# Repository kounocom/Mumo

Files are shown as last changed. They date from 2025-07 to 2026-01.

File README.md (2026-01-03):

# Mumo - Compact ICM-45686+QMC6309 Module

A compact 13×18mm IMU module featuring the TDK InvenSense ICM-45686 6-axis IMU with integrated 32.768kHz clock and QST QMC6309 3-axis magnetometer.

PCB Image

## Features

- **Compact Design**: 13×18mm form factor
- **High-Performance IMU**: TDK InvenSense ICM-45686 6-axis IMU with integrated 32.768kHz clock for precise output timesteps
- **3-Axis Magnetometer**: QST QMC6309 for 9-DOF sensing
- **Connectivity**: Castellated holes for flat mounting on compatible carrier PCBs
- **Power Optimization**: Solder bridges to disconnect I2C pull-ups for improved power efficiency when using SPI
- **Easily Configurable I2C Address**: Solder bridge for SD0 pin to change I2C address from `0x69` to `0x68`

## Compatibility

The pinout is **mostly compatible** with popular BMI160 and LSM6DS3 modules found on Amazon and AliExpress, with these differences:

- **OSDO**: Functions as VIN on AliExpress modules
- **CLK_CTL**: Not present on AliExpress modules

## Schematic

Schematic

## Ordering Information

### Important Notes

⚠️ **IMU Pin 7**: Pin 7 of the IMU is intentionally disconnected as recommended for the ICM-45686. If substituting with another IMU that requires pin 7 as GND, modify the PCB to connect IMU pin 7 to ground.

⚠️ **Surface Finish**: ENIG surface finish is recommended for easier soldering and better reliability with the BGA magnetometer.

⚠️ **Castellated Holes**: While castellated holes significantly increase manufacturing cost, they enable flat soldering onto carrier boards. Consider your application requirements before deciding to omit them.

## License

See [LICENSE.md](LICENSE.md) for license information.

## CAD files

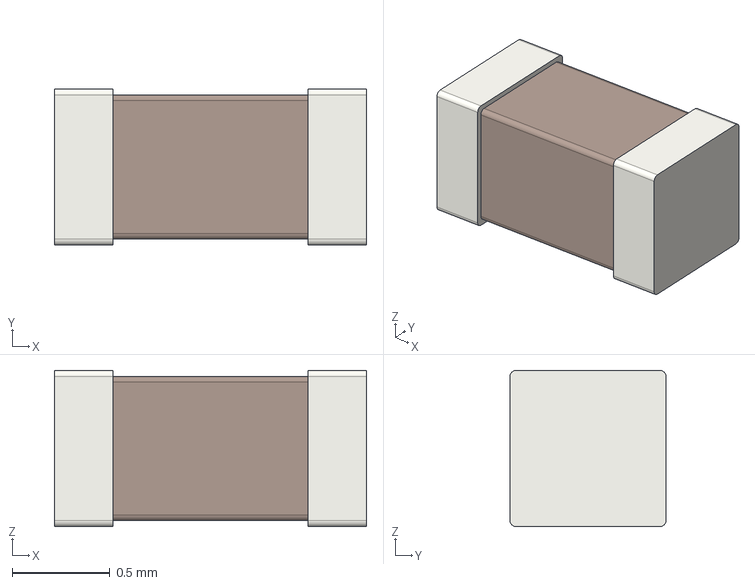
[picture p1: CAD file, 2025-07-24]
Mumo Data/Mumo Models/C_0603_1608Metric.step
1.60 x 0.8 x 0.8 mm

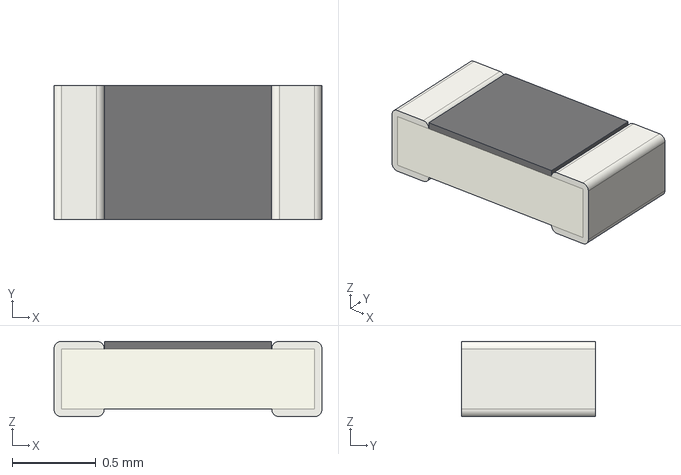
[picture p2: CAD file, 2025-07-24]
Mumo Data/Mumo Models/R_0603_1608Metric.step
1.60 x 0.8 x 0.45 mm

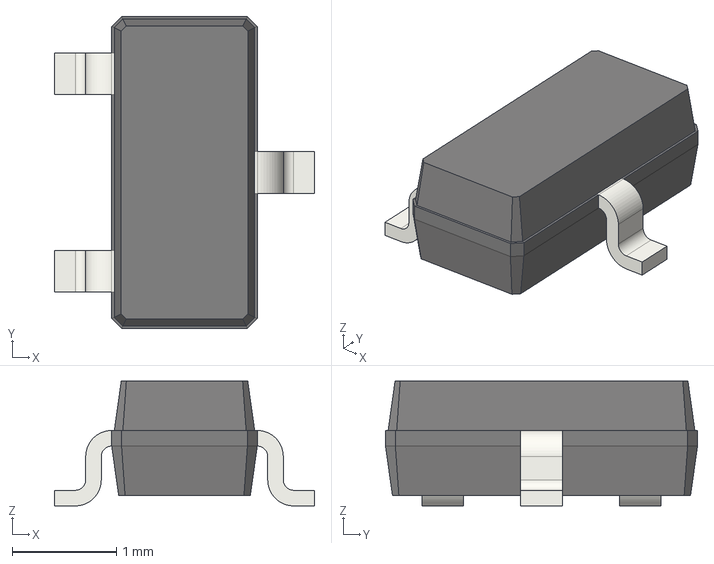
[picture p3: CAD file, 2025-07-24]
Mumo Data/Mumo Models/SOT-23.step
2.50 x 3.00 x 1.20 mm

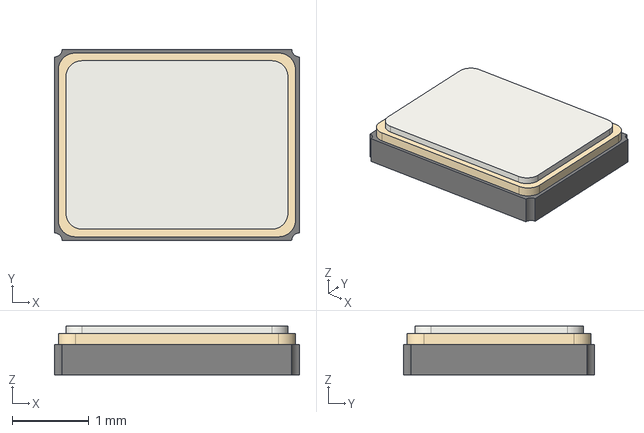
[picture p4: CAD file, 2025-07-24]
Mumo Data/Mumo Models/Crystal_SMD_3225-4Pin_3.2x2.5mm.step
3.20 x 2.50 x 0.64 mm

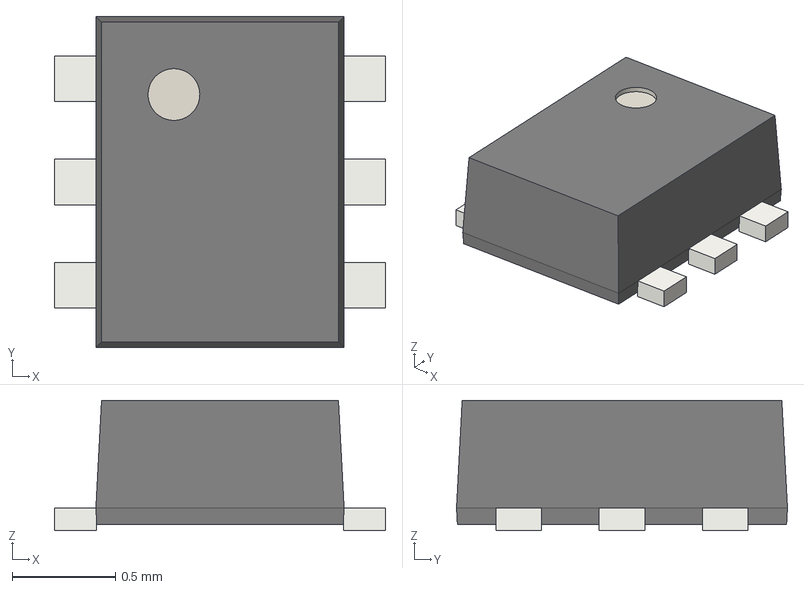
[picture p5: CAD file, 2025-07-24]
Mumo Data/Mumo Models/SOT-563.step
1.60 x 1.60 x 0.63 mm

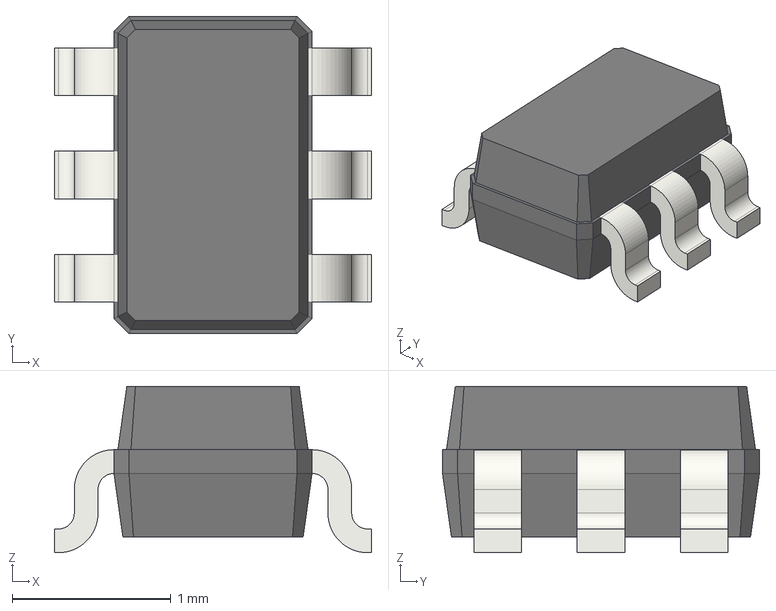
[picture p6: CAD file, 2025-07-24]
Mumo Data/Mumo Models/SOT-363_SC-70-6.step
2.00 x 2.00 x 1.05 mm

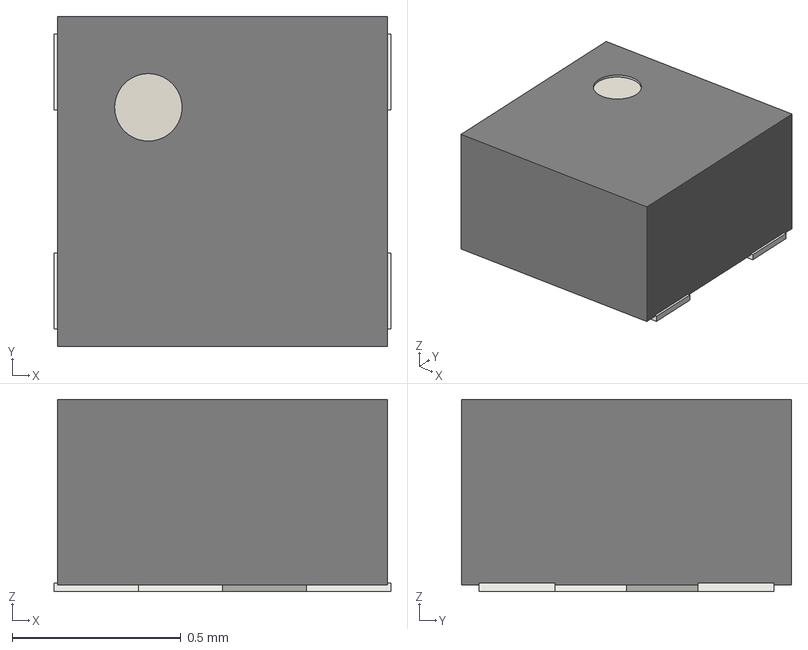
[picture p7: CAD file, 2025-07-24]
Mumo Data/Mumo Models/UDFN-4-1EP_1x1mm_P0.65mm_EP0.48x0.48mm.step
1.00 x 0.98 x 0.57 mm

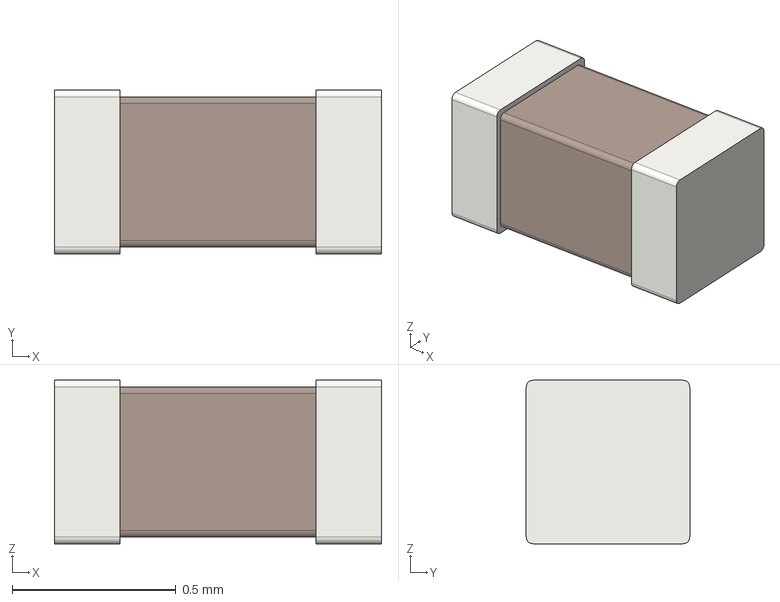
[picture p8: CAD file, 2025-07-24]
Mumo Data/Mumo Models/C_0402_1005Metric.step
1.00 x 0.5 x 0.5 mm

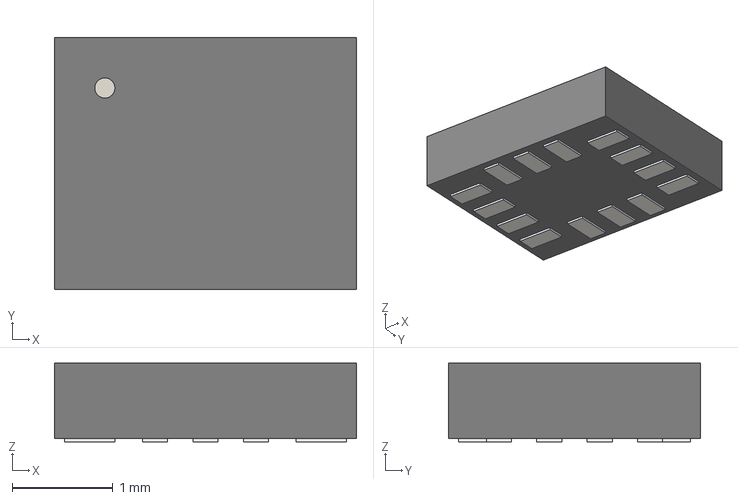
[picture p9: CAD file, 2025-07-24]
Mumo Data/Mumo Models/Bosch_LGA-14_3x2.5mm_P0.5mm.step
3.00 x 2.50 x 0.78 mm

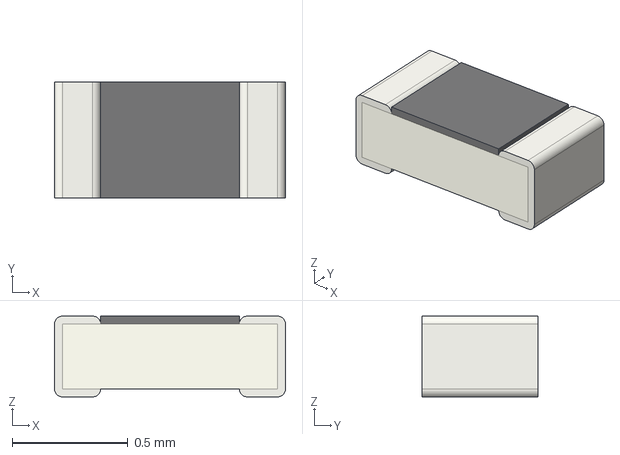
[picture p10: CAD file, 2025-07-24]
Mumo Data/Mumo Models/R_0402_1005Metric.step
1.00 x 0.5 x 0.35 mm

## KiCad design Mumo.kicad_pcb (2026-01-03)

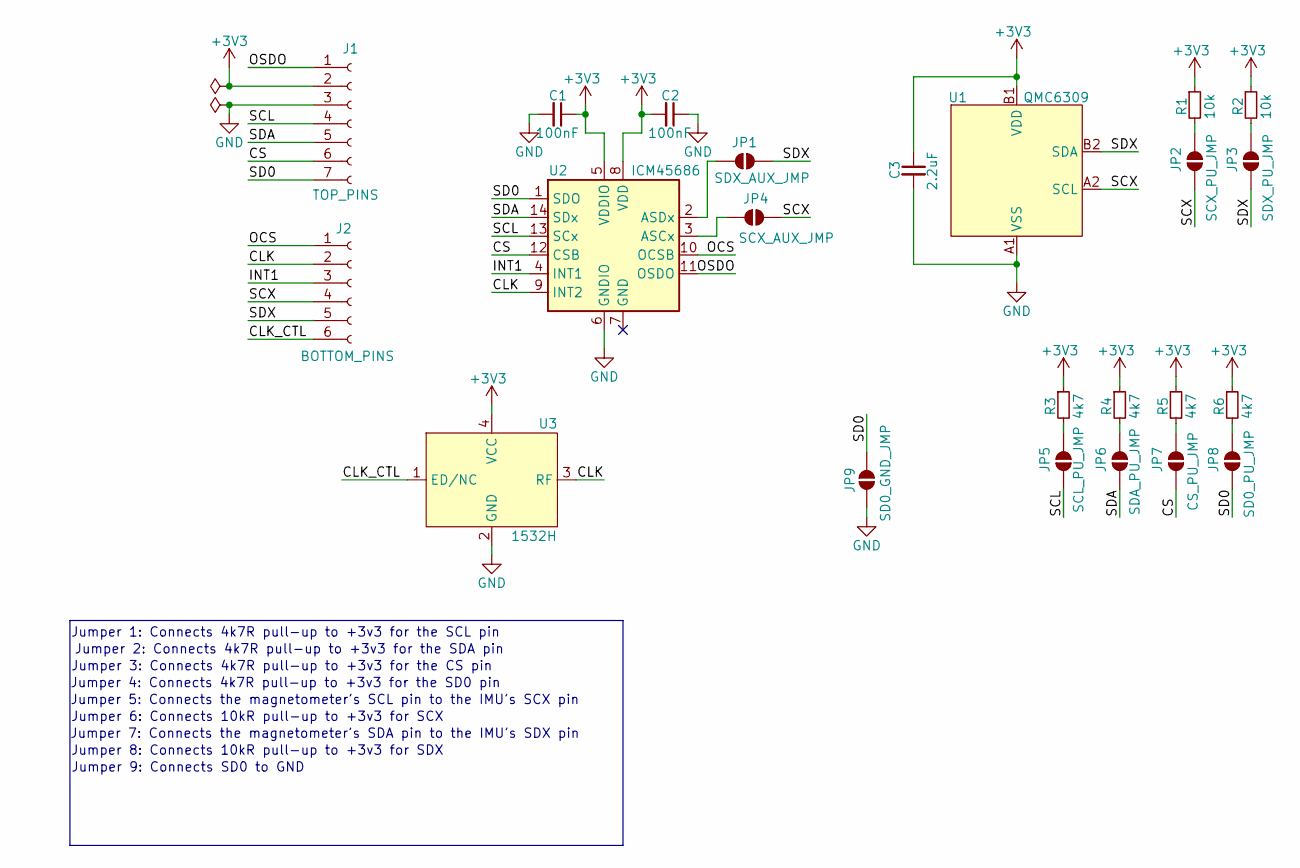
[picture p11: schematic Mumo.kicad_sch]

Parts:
C1, C2: 100nF; C_0402; MPN C1525
C3: 2.2uF; C_0603; MPN C57895
J1: TOP_PINS; TopPins; MPN N/A
J2: BOTTOM_PINS; BottomPins
JP1: SDX_AUX_JMP; JMP_CLSD
JP2: SCX_PU_JMP; JMP_CLSD
JP3: SDX_PU_JMP; JMP_CLSD
JP4: SCX_AUX_JMP; JMP_CLSD
JP5: SCL_PU_JMP; JMP_CLSD
JP6: SDA_PU_JMP; JMP_CLSD
JP7: CS_PU_JMP; JMP_CLSD
JP8: SD0_PU_JMP; JMP_CLSD
JP9: SD0_GND_JMP; JMP; MPN N/A
R1, R2: 10k; R_0402; MPN C25744
R3, R4, R5, R6: 4k7; R_0402; MPN C25900
U1: QMC6309; MPN C5439871
U2: ICM45686; IMU; MPN C22459454
U3: 1532H; CLK; MPN C709192

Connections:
+3V3: C1.1, C2.2, C3.1, J1.2, R1.1, R2.1, R3.1, R4.1, R5.1, R6.1, U1.B1 (VDD), U2.5 (VDDIO), U2.8 (VDD), U3.4 (VCC)
/CLK: J2.2, U2.9 (INT2), U3.3 (RF)
/CLK_CTL: J2.6, U3.1 (ED/NC)
/CS: J1.6, JP7.1 (A), U2.12 (CSB)
/INT1: J2.3, U2.4 (INT1)
/OCS: J2.1, U2.10 (OCSB)
/OSDO: J1.1, U2.11 (OSDO)
/SCL: J1.4, JP5.1 (A), U2.13 (SCx)
/SCX: J2.4, JP2.1 (A), JP4.2 (B), U1.A2 (SCL)
/SD0: J1.7, JP8.1 (A), JP9.2 (B), U2.1 (SDO)
/SDA: J1.5, JP6.1 (A), U2.14 (SDx)
/SDX: J2.5, JP1.2 (B), JP3.1 (A), U1.B2 (SDA)
GND: C1.2, C2.1, C3.2, J1.3, JP9.1 (A), U1.A1 (VSS), U2.6 (GNDIO), U3.2 (GND)
unnamed: JP1.1 (A), U2.2 (ASDx)
unnamed: JP2.2 (B), R1.2
unnamed: JP3.2 (B), R2.2
unnamed: JP4.1 (A), U2.3 (ASCx)
unnamed: JP5.2 (B), R3.2
unnamed: JP6.2 (B), R4.2
unnamed: JP7.2 (B), R5.2
unnamed: JP8.2 (B), R6.2

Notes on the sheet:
Jumper 9: Connects SD0 to GND
Jumper 2: Connects 4k7R pull-up to +3v3 for the SDA pin
Jumper 7: Connects the magnetometer's SDA pin to the IMU's SDX pin
Jumper 5: Connects the magnetometer's SCL pin to the IMU's SCX pin
Jumper 6: Connects 10kR pull-up to +3v3 for SCX
Jumper 4: Connects 4k7R pull-up to +3v3 for the SD0 pin
Jumper 3: Connects 4k7R pull-up to +3v3 for the CS pin
Jumper 8: Connects 10kR pull-up to +3v3 for SDX
Jumper 1: Connects 4k7R pull-up to +3v3 for the SCL pin

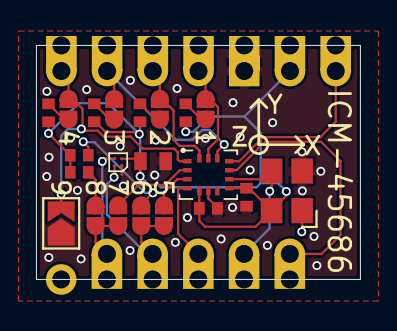
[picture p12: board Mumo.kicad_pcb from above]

Board: 4 copper layers, 18.0 x 13.0 mm, 23 parts (0 on the bottom side), 21 nets.

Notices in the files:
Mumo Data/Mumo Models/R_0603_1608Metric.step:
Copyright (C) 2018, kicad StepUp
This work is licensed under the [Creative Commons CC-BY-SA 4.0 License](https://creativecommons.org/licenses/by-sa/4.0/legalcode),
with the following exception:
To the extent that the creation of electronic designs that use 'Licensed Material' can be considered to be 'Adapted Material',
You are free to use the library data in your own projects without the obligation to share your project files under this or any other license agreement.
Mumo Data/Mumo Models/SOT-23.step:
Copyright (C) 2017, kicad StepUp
